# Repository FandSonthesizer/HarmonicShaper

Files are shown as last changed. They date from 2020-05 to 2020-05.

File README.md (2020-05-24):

# HarmonicShaper

This is a project where we take an audio-input signal, filter a rectangular wave from it and use that to create harmonics below or above the input signal.

Features:
- can be used directly with electric guitar output or a synthesizer output.
- 4 harmonic waves can be generated
- selectable waveform: SIN, TRI, RMP, SAW and Square
- Clean and harmonic blend mixer
- harmonics adjustable from 7 undertones to 7 overtones 

It is based on our Essential Shield.

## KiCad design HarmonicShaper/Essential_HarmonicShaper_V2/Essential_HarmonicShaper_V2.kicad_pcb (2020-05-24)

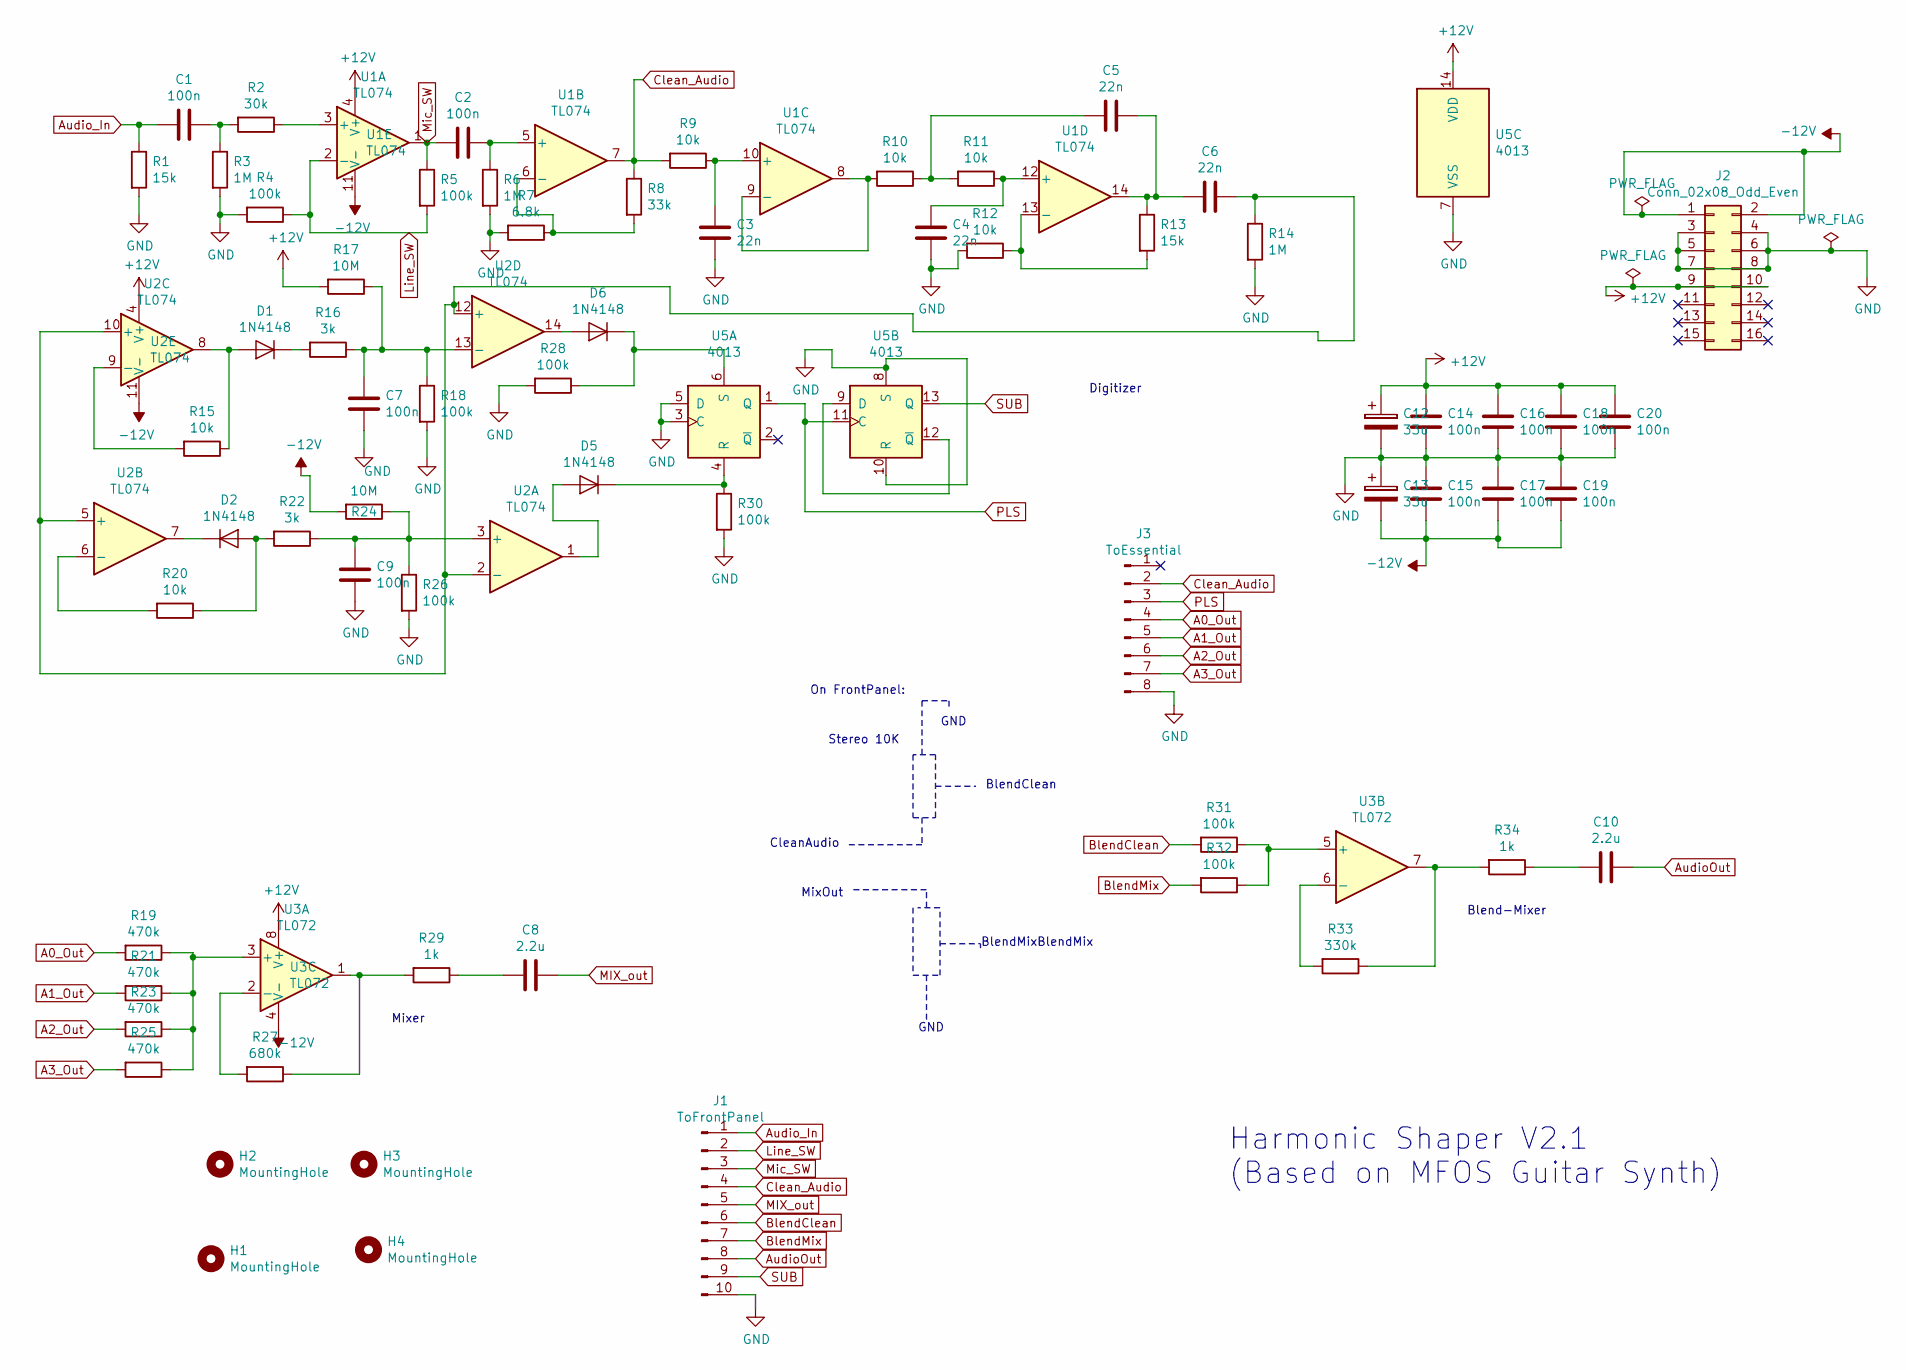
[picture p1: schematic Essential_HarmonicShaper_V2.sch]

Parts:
C1, C2, C7, C9, C14, C15, C16, C17, C18, C19, C20: 100n; Kondensator_Keramik
C3, C4, C5, C6: 22n; Kondensator_Keramik
C8, C10: 2.2u; Kondensator_Keramik
C12, C13: 33u; Elko_D6.3mm_P2.50mm
D1, D2, D5, D6: 1N4148; Diode_Horizontal
H1, H2, H3, H4: MountingHole; MountHole
J1: ToFrontPanel; PinHeader_1x10_P2.54mm_Vertical
J2: Conn_02x08_Odd_Even; PinHeader_2x08_P2.54mm_Vertical
J3: ToEssential; PinHeader_1x08_P2.54mm_Vertical
R1, R13: 15k; Widerstand_liegend
R2: 30k; Widerstand_liegend
R3, R6, R14: 1M; Widerstand_liegend
R4, R5, R18, R26, R28, R30, R31, R32: 100k; Widerstand_liegend
R7: 6.8k; Widerstand_liegend
R8: 33k; Widerstand_liegend
R9, R10, R11, R12, R15, R20: 10k; Widerstand_liegend
R16, R22: 3k; Widerstand_liegend
R17, R24: 10M; Widerstand_liegend
R19, R21, R23, R25: 470k; Widerstand_liegend
R27: 680k; Widerstand_liegend
R29, R34: 1k; Widerstand_liegend
R33: 330k; Widerstand_liegend
U1, U2: TL074; DIP-14_W7.62mm_LongPads
U3: TL072; DIP-8_W7.62mm_Socket_LongPads
U5: 4013; DIP-14_W7.62mm_LongPads

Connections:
+12V: C12.1, C14.1, C16.1, C18.1, C20.1, J2.9, J2.10, R17.2, U1.4 (V+), U2.4 (V+), U3.8 (V+), U5.14 (VDD)
-12V: C13.2, C15.2, C17.2, C19.2, J2.1, J2.2, R24.2, U1.11 (V-), U2.11 (V-), U3.4 (V-)
A0_Out: J3.4, R19.2
A1_Out: J3.5, R21.2
A2_Out: J3.6, R23.2
A3_Out: J3.7, R25.2
AudioOut: C10.2, J1.8
Audio_In: C1.1, J1.1, R1.1
BlendClean: J1.6, R31.2
BlendMix: J1.7, R32.2
Clean_Audio: J1.4, J3.2, R8.1, R9.2, U1.7
GND: C3.2, C4.2, C7.2, C9.2, C12.2, C13.1, C14.2, C15.1, C16.2, C17.1, C18.2, C19.1, C20.2, J1.10, J2.3, J2.4, J2.5, J2.6, J2.7, J2.8, J3.8, R1.2, R3.2, R4.2, R6.2, R7.2, R12.2, R14.2, R18.2, R26.2, R28.2, R30.2, U5.3 (C), U5.5 (D), U5.7 (VSS), U5.8 (S), U5.10 (R)
Line_SW: J1.2, R4.1, R5.2, U1.2 (-)
MIX_out: C8.2, J1.5
Mic_SW: C2.1, J1.3, R5.1, U1.1
unnamed: C1.2, R2.2, R3.1
unnamed: C2.2, R6.1, U1.5 (+)
unnamed: C3.1, R9.1, U1.10 (+)
unnamed: C4.1, R11.1, U1.12 (+)
unnamed: C5.1, C6.2, R13.1, U1.14
unnamed: C5.2, R10.1, R11.2
unnamed: C6.1, R14.1, U2.2 (-), U2.5 (+), U2.10 (+), U2.12 (+)
unnamed: C7.1, R16.1, R17.1, R18.1, U2.13 (-)
unnamed: C8.1, R29.1
unnamed: C9.1, R22.1, R24.1, R26.1, U2.3 (+)
unnamed: C10.1, R34.1
unnamed: D1.1 (K), R16.2
unnamed: D1.2 (A), R15.1, U2.8
unnamed: D2.1 (K), U2.7
unnamed: D2.2 (A), R20.1, R22.2
unnamed: D5.1 (K), R30.1, U5.4 (R)
unnamed: D5.2 (A), U2.1
unnamed: D6.1 (K), R28.1, U5.6 (S)
unnamed: D6.2 (A), U2.14
unnamed: R2.1, U1.3 (+)
unnamed: R7.1, R8.2, U1.6 (-)
unnamed: R10.2, U1.8, U1.9 (-)
unnamed: R12.1, R13.2, U1.13 (-)
unnamed: R15.2, U2.9 (-)
unnamed: R19.1, R21.1, R23.1, R25.1, U3.3 (+)
unnamed: R20.2, U2.6 (-)
unnamed: R27.1, R29.2, U3.1
unnamed: R27.2, U3.2 (-)
unnamed: R31.1, R32.1, U3.5 (+)
unnamed: R33.1, R34.2, U3.7
unnamed: R33.2, U3.6 (-)
unnamed: U5.9 (D), U5.12 (~Q)
PLS: J3.3, U5.1 (Q), U5.11 (C)
SUB: J1.9, U5.13 (Q)

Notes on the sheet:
Harmonic Shaper V2.1 (Based on MFOS Guitar Synth)
Mixer
Digitizer
Blend-Mixer
Stereo 10K
GND
MixOut
CleanAudio
On FrontPanel:
BlendClean
BlendMixBlendMix

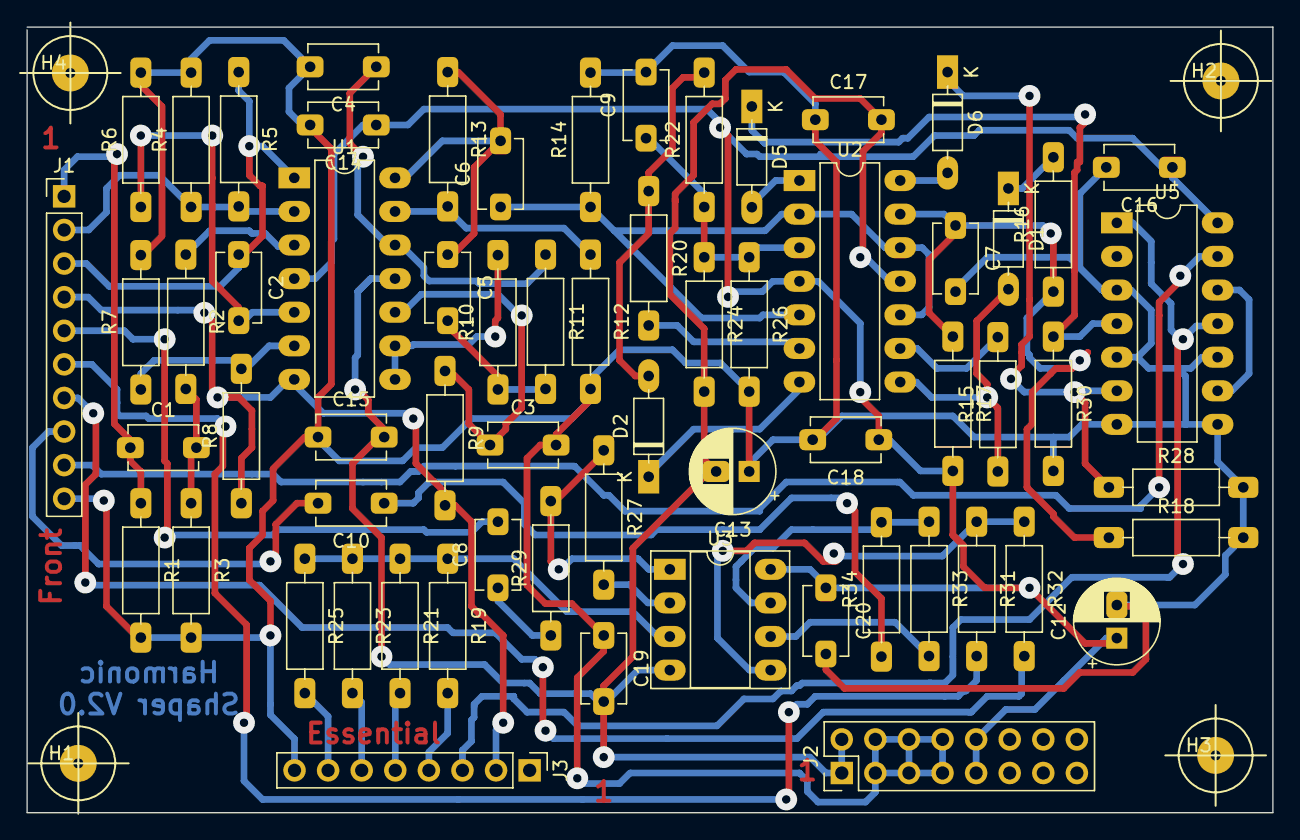
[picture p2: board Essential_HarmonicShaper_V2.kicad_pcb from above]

Board: 2 copper layers, 94.2 x 59.4 mm, 68 parts (0 on the bottom side), 49 nets.

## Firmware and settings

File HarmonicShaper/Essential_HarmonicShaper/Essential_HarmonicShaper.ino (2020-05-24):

#include "Voice.h"
#include "PWM.h"
#include "Dac.h" 
#include "Controls.h" 

uint32_t triggerCount, mil;
uint64_t gTick = 0;
uint64_t startMeasureTime = 0, measureFreqCounter, triggerTime;
uint64_t lastActiveTime = 0;

uint64_t period = 0;
const uint64_t maxPeriod = 2000000;

int uTick = 0, globalTic;
uint16_t freq = 0, q;
float f2 = 0.0;
uint16_t measureFreqInterval = 1000; //0.1 sec Interval

uint64_t lastSampleTime = 0;
uint16_t sampleInterval = 50;
int controlNumber = 0;


const uint16_t highMuteTime = 100, lowMuteTime = 3000; // [ms]
uint16_t muteTime = highMuteTime;
const bool align = false; 
bool updateC = true, mute = false;
int lifeRate = 499;
bool test = false;
bool start = true, life;


void setup() {
  pinMode(PC13, OUTPUT); //  Onboard LED
  initControls();
  initDac();
  initPwm();
  initVoices();
  initISR();
  
  
  pinMode(clockPin, INPUT_PULLDOWN);
  attachInterrupt(clockPin, TriggerReceived, FALLING); //LOW, FALLING, RISING, CHANGE
  Serial.begin(115200);
}


  
void loop() {
  if (millis() > 500 && start) {
    start = false;
    if (align) {
      //Serial.println("Start Alignment");
      pwmWrite(PWM_OUT, maxPWMAmplitude);
      pwmWrite(PWM_OUT2, maxPWMAmplitude);
      sendToDAC(DAC0, maxDACAmplitude);
      sendToDAC(DAC1, maxDACAmplitude);
    }
    else {
      Serial.println("Harmonic Shaper");
    }
    startMeasureTime = 0;
    triggerCount = 0;
  }
  else {
   // 0-4095
   /*uint64_t actual = micros();
   uint16_t diff = lastSampleTime - actual;
   if (diff >= sampleInterval ) {
     lastSampleTime = actual;
     uint16_t v = adc_read(ADC2, PA2);
     sendToDAC(DAC0, v);
   }
   test = !test;
   */
  /* Serial.print(period);
   Serial.print(" ");
   Serial.print(period > 0);
   Serial.print(" step=");
   Serial.print(harmonys[2].step);
   Serial.print(" div=");
   Serial.println(harmonys[2].divider);
   */
   
    
   // Update analog input:
  if (!start && updateC) {
    uTick = false;
    updateAnalogControls(controlNumber);
    controlNumber++;
    if (controlNumber >= MAXPOT) {
      controlNumber = 0;
     
    }
    updateC = false;
   /* Serial.print(harmonys[0].step);
    Serial.print(" ");
    Serial.println(harmonys[0].vOutput);
    */
  }
  
  uint16_t diff = mil - lastActiveTime; // time since last trigger
  if (!mute && diff > muteTime) {
    mute = true;
 /*  Serial.print("Go Mute! muteTime=");
   Serial.print( muteTime);
  Serial.print(" diff=");
  Serial.print(diff);
  Serial.print("mute=");
  Serial.println(mute);
  */
    
  }
  digitalWrite(OUT1, mute?0:1); 
  }
}

void updateAnalogControls(int which) {
  // Buttons
  int old,val,diff, r_val, shift, high;

  shift = digitalRead(buttons[SHIFT].portPin) == 0;
  high = digitalRead(buttons[HIGH_SW].portPin);
  muteTime = (high == 0)?highMuteTime:lowMuteTime;
 /* Serial.print("Shift=");
  Serial.print(shift);
  Serial.print(" High=");
  Serial.println(high);
  */
  switch(which) {
    case 0:
      //------------Waveform: ---------------------------
      if (readAnalogChannel(P_WAVEFORM, mil)) {
          int sel = SIN;
          int val = a_channel[P_WAVEFORM].Avalue;
          if (val > 3950 )
            sel = SQR;  
          else if (val > 2800 )
            sel = RMP;  
          else if (val > 1200 )
            sel = SAW;  
          else if (val > 200 )
            sel = TRI;     
          for (int n = 0; n < VOICES; n++)
            harmonys[n].waveForm = sel;
      }
      break;
    case 1:
      //------------Volume/Divider poti: ---------------------------
      if (readAnalogChannel(P_H1, mil)) {
        if (shift) {
            setVolume(a_channel[P_H1].Avalue, 0);
        }
        else {
            setDivider(a_channel[P_H1].Avalue, 0);
        }
      }
      break;
    case 2:
      //------------Volume/Divider poti: ---------------------------
      if (readAnalogChannel(P_H2, mil)) {
        if (shift)
            setVolume(a_channel[P_H2].Avalue, 1);
        else
            setDivider(a_channel[P_H2].Avalue, 1);
      }
      break;
    case 3:
      //------------Volume/Divider poti: ---------------------------
      if (readAnalogChannel(P_H3, mil)) {
        if (shift)
            setVolume(a_channel[P_H3].Avalue, 2);
        else
            setDivider(a_channel[P_H3].Avalue, 2);
      }
      break;
    case 4:
      //------------Volume/Divider poti: ---------------------------
      if (readAnalogChannel(P_H4, mil)) {
        if (shift)
            setVolume(a_channel[P_H4].Avalue, 3);
        else
            setDivider(a_channel[P_H4].Avalue, 3);
      }
      break;
  }
}
void initISR() {
  /** 
   *  Setup Timer 2 to 25u (40000 per second)
   */
  Timer2.setMode(TIMER_CH1, TIMER_OUTPUTCOMPARE);
  Timer2.setPeriod(isr_cnt);                          // in microseconds (100u = 10kHz)
  Timer2.setCompare(TIMER_CH1, 1);                   
  Timer2.attachInterrupt(TIMER_CH1, handler_Synth);   // in this routine the synth moves through the wave-table
}

/**
 * Here we measure one period of the trigger signal
 */
void TriggerReceived() {
 uint64_t actual = micros();
  period = actual - triggerTime;
 // Serial.println(period);
  if (period > 40 && period  < maxPeriod) { // Range: 26KHz to 0.5 Hz
   // Serial.println("Valid!");
    uint32_t base = z20 / period;
    for (int n = 0; n  < VOICES; n++) {
      
       if (harmonys[n].multiply)
          harmonys[n].step = base * harmonys[n].divider;
       else 
          harmonys[n].step = base / harmonys[n].divider;   
      // harmonys[n].step = base; // test : no change
    }
  }
  else {
    period = 0;
  //  Serial.println("Invalid!");
  }
  triggerTime = actual;
  lastActiveTime = mil;
  if (mute) {
    //Serial.println("Unmute!");
    mute = false;
  }
  
 // life = !life;
 // digitalWrite(PC13, life); // Lifesign
}

void handler_Synth(void) {
  gTick++;   // count up all the time at 40khz
  globalTic++;            
  if (globalTic > 39) {
    globalTic = 0;        // 40 tics at 40 khz is one millisec.
    // one millisecond has passed--------------
    mil++;                // increase millisecond tic, used for button debounce etc.
     // Lifesign of interrupt routine, let the onboard LED blink
    uint16_t dif = mil - q;
     uTick++;
    if (uTick > 24) { // analog in update every 25 ms 
       updateC = true;
       uTick = 0;
    }
    if (dif > lifeRate ) {  // Lifesign routine 499
      q = mil;
      life = !life;
      digitalWrite(PC13, life); // Lifesign
    }
  }
 
  if (!start && !align && period > 0 && !mute) {
    // doVoice
     
       uint16_t ch2 = 0;
       addStep(0);
       ch2 = harmonys[0].vOutput + maxDACAmplitude2;
       sendToDAC(DAC0, ch2); 
       
      
       addStep(1);
       sendToDAC(DAC1, harmonys[1].vOutput + maxDACAmplitude2); 

       addStep(2);
       ch2 = (harmonys[2].vOutput * maxPWMAmplitude2) / 2047; // use maxAmplitude to scale it
       ch2 += maxPWMAmplitude2;
       pwmWrite(PWM_OUT, ch2); 

       addStep(3);
       ch2 = (harmonys[3].vOutput * maxPWMAmplitude2) / 2047; // use maxAmplitude to scale it
       ch2 += maxPWMAmplitude2;
       pwmWrite(PWM_OUT2, ch2); 
       
   }
   
}


  

  

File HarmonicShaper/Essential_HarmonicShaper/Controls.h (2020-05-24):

// Ky-040 encoder
const int ky_clk  = PB14;   // Connected to CLK on KY-040
const int ky_dt   = PA12;   // Connected to DT on KY-040
const int ky_sw   = PA15;   // Der Switch wird mit Pin D2 Verbunden. 

const int CHANGELIMIT = 3000;
const int adjustDiff = 110, stableDiff = 30;
const int stableTime = 800; //[ms]

const uint16_t P_WAVEFORM  = 0;
const uint16_t P_H1  = 1;
const uint16_t P_H2  = 2;
const uint16_t P_H3  = 3;
const uint16_t P_H4  = 4;  //
const uint16_t MAXPOT  = 5;
const int clockPin = PB4;

const int AVERAGE =       10;     // For the gliding average method (LP filter for noisy analog values)



const int VCO_diff = 1360;
const int LFO_diff = 450;
int VCO_diff2 = VCO_diff / 2;
int LFO_diff2 = LFO_diff / 2;


typedef struct {
  bool adjustStart;
  bool adjustEnd;
  uint32_t adjustTime;
  uint16_t Avalue;
  uint32_t avgsum;
  uint16_t mcount;
  uint16_t pin;
} Analog_type;
Analog_type a_channel[MAXPOT]; 

// Encoder vars:
uint32_t TimeOfLastDebounce = 0;
uint16_t DelayofDebounce = 10;
int16_t encoderPosCount = 0; 
uint16_t dtVal_Old = 1;
boolean bCW;
/*
LFO LED @analog pins
ADSR1 LED
ADSR2 LED

PWM1 = CV     - analog 1
PWM2 = ADSR1  - analog 2
DAC0 = LFO    - analog 3
DAC1 = ADSR2  - analog 4
*/
//Switches & buttons
const uint16_t ENCODERBT  = 0;  // Switch on encoder
const uint16_t SHIFT  = 1;  // 
const uint16_t HIGH_SW  = 2;  // 
const int noOfButtons = 3;

const int OUT1 = PB9;           // to analog adsr trigger on note on
const int OUT2 = PC15;          // Aftertouch - glide in
const int OUT3 = PB8;           // Midi clock pulses to keystep 24/4
const int OUT4 = PA7;           // NC

typedef struct {
  int portPin;                 // Pin Nunber to read;
  uint16_t debounceDelay;      // debounceDelay = 50;    // the debounce time; increase if the output flickers
  uint16_t lastDebounceTime;   // lastDebounceTime = 0;  // the last time the output pin was toggled
  uint16_t lastButtonState;    // actual state
  uint16_t buttonState; 
  bool changeInprogress = false;
 } Button_type;
Button_type buttons[noOfButtons];

void initControls() {
  // output Pins:
  pinMode(PC13, OUTPUT); // 
  pinMode(OUT1, OUTPUT);  // o1
  pinMode(OUT2, OUTPUT); // o2
  pinMode(OUT3, OUTPUT);  // o3
  pinMode(OUT4, OUTPUT); // o4
  
  // define and init input pins:
  buttons[ENCODERBT].portPin   = ky_sw;  // ky
  buttons[SHIFT].portPin       = PB5;   // Input 1
  buttons[HIGH_SW].portPin     = PB6;   // Input 2
  for(int n = 0; n < noOfButtons; n++) {
    buttons[n].debounceDelay = 200;  // 4000
    buttons[n].lastDebounceTime = 0;
    pinMode(buttons[n].portPin, INPUT_PULLUP);
    buttons[n].lastButtonState = digitalRead(buttons[n].portPin);
    buttons[n].buttonState = buttons[n].lastButtonState;
    buttons[n].changeInprogress = false;
  }

  // Define the analog input pins: 
  a_channel[P_WAVEFORM].pin   = PA4;
  a_channel[P_H1].pin    = PA0;
  a_channel[P_H2].pin  = PA1;
  a_channel[P_H3].pin  = PA2; 
  a_channel[P_H4].pin     = PA3;
 
  /*
  pin[P_LFO_PWM]      = PA7;
*/
  for (int n = 0; n < MAXPOT; n++) {
     a_channel[n].mcount = 0;
     a_channel[n].avgsum = 0;
     a_channel[n].Avalue = 0;
     pinMode(a_channel[n].pin, INPUT_ANALOG);
  }

 
}

/**
 * Gliding Average value.
 * This method simulates a capacitor to even out the noisyness of the stm32's adc.
 * @param newval the ne value, read from adc
 * @param potCh which channel to read
 */
uint32 glidingAverage(uint16 newval, uint16 potCh) {
   uint32 average = 0; 
   if (a_channel[potCh].mcount < AVERAGE) { // initial loading of the capacitor
      a_channel[potCh].avgsum += newval;
      average = a_channel[potCh].avgsum / a_channel[potCh].mcount;
      a_channel[potCh].mcount++;
   }
   else {
    // now hold and change the charge
      a_channel[potCh].avgsum -= a_channel[potCh].avgsum / AVERAGE;
      a_channel[potCh].avgsum += newval;
      average = a_channel[potCh].avgsum / AVERAGE;
   }
   return average;
}


/**
 * read an analog channel. Store value in Avalue[potCh]
 * @param potCh the analoge channel to read
 * @return true if the value was changed
 */
bool updateAnalogChannel(uint16 potCh) {
   // Read the Potentiometer value 
   bool c = false;
   /*Serial.print("Channel=");
   Serial.print(potCh);
   */
   int Nscale = adc_read(ADC2, a_channel[potCh].pin);       // ADC2 read noisy voltage value from pot.
   //Serial.print(" Nscale=");
  // Serial.print(Nscale);
   uint32 m = glidingAverage(  Nscale, potCh );   // Add the new adc value into a gliding average value
   //Serial.print(" GAverage=");
  // Serial.print(m);
   uint32 d = abs(m - a_channel[potCh].Avalue);
   //Serial.print(" diff=");
   //Serial.println(d);
   if (d > 5) {
      a_channel[potCh].Avalue = m;
      c = true;
   }
   return c;
}
// ----------- switches amd buttons: -------------------------
/**
 * @param btn number of the button/switch
 * @param mil is in 1/10 milliseconds
 * @return true if changed
 */
boolean readInputPin(uint32_t mil, int btn) {
  // Reset Button:
    bool res = false;
    uint16_t bt = digitalRead(buttons[btn].portPin); // 0=clear, 1 = neutral
   // Serial.println(bt);
    uint32_t diff = mil - buttons[btn].lastDebounceTime;
    //  Serial.println(diff);
    if (buttons[btn].lastButtonState != bt && diff > buttons[btn].debounceDelay ) {
      if (bt == 0) {
        // pressed
          buttons[btn].lastDebounceTime = mil;
        }
    }
    res = buttons[btn].lastButtonState != bt;
    buttons[btn].lastButtonState = bt; // here we save the actual button state
    return res;
}

boolean buttonWasPressed(uint32_t gtick, int btn) {
  // Reset Button:
    bool res = false;
    uint16_t bt;
    if (!buttons[btn].changeInprogress) {
        bt = digitalRead(buttons[btn].portPin); // 0=pressed, 1 = not pressed
        if (bt != buttons[btn].lastButtonState) {
          /*Serial.print("change started! oldbt=");
          Serial.print(buttons[btn].lastButtonState);
          Serial.print(" gtick=");
          Serial.print(gtick);
          Serial.print(" delay=");
          Serial.println(buttons[btn].debounceDelay);
          */
          buttons[btn].changeInprogress = true;
          buttons[btn].lastDebounceTime = gtick;
        }
    }
    else {
       uint32_t diff = gtick - buttons[btn].lastDebounceTime;
      // Serial.print("Changing diff=");
      // Serial.println(diff);
       if (diff > buttons[btn].debounceDelay) {
          buttons[btn].changeInprogress = false;
          buttons[btn].lastButtonState = buttons[btn].buttonState;
          bt = digitalRead(buttons[btn].portPin); 
          if (bt != buttons[btn].buttonState){
           buttons[btn].buttonState = bt;
            //Serial.print("Change wait done bt=");
            //Serial.println(bt);
            res = true;
         }
       }
    }
    
    return res;
}
//--- Encoder ------------------------
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
